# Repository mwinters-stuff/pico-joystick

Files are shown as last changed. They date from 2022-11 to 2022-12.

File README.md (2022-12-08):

# vscode-devcontainer-raspberrypi-pico

## Usage

Clone or download repository, copy the contents of .devcontainer into your project
Remove any existing "build" directory.

Open the folder, and allow the container to build.

# To know
* SDK is installed in /pico-sdk
* All USB devices are exported to container - so the picoprobe can be found and used.
* USB Device /dev/ttyACM0 is exported to container for monitoring

## This container includes
* pico-sdk
* openocd - compiled for picoprobe
* picotool
* bootterm (for serial monitoring) - see https://github.com/wtarreau/bootterm

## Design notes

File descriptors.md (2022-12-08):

# Thrustmaster

```
> sudo usbhid-dump -a3:99 -i0 -t0 | grep -v : | xxd -r -p | hidrd-convert -o spec
Usage Page (Desktop),                           ; Generic desktop controls (01h)
Usage (Joystick),                               ; Joystick (04h, application collection)
Collection (Application),
    Usage Page (Button),                        ; Button (09h)
    Usage Minimum (01h),
    Usage Maximum (10h),
    Logical Minimum (0),
    Logical Maximum (1),
    Physical Minimum (0),
    Physical Maximum (1),
    Report Size (1),
    Report Count (16),
    Input (Variable),
    Usage Page (Desktop),                       ; Generic desktop controls (01h)
    Usage (Hat Switch),                         ; Hat switch (39h, dynamic value)
    Logical Minimum (0),
    Logical Maximum (7),
    Physical Minimum (0),
    Physical Maximum (315),
    Unit (Degrees),
    Report Size (4),
    Report Count (1),
    Input (Variable, Null State),
    Input (Constant),
    Usage Page (Desktop),                       ; Generic desktop controls (01h)
    Usage (X),                                  ; X (30h, dynamic value)
    Logical Minimum (0),
    Logical Maximum (16383),
    Physical Minimum (0),
    Physical Maximum (16383),
    Unit,
    Report Size (14),
    Report Count (1),
    Input (Variable),
    Report Size (2),
    Input (Constant),
    Usage (Y),                                  ; Y (31h, dynamic value)
    Report Size (14),
    Input (Variable),
    Report Size (2),
    Input (Constant),
    Usage (Rz),                                 ; Rz (35h, dynamic value)
    Usage (Slider),                             ; Slider (36h, dynamic value)
    Logical Minimum (0),
    Logical Maximum (255),
    Physical Minimum (0),
    Physical Maximum (255),
    Unit,
    Report Size (8),
    Report Count (2),
    Input (Variable),
    Usage Page (FF00h),                         ; FF00h, vendor-defined
    Logical Maximum (65535),
    Usage (01h),
    Report Size (8),
    Report Count (4),
    Feature (Variable, No Preferred, Volatile),
End Collection
```

# CAT Stick.
mwinters@mwinters-nz-ll:~/src/hidrd$ sudo usbhid-dump -a3:101 -i0 -t0 | grep -v : | xxd -r -p | hidrd-convert -o spec
```
Usage Page (Desktop),       ; Generic desktop controls (01h)
Usage (Joystick),           ; Joystick (04h, application collection)
Collection (Application),
    Report ID (12),
    Usage (X),              ; X (30h, dynamic value)
    Logical Minimum (1),
    Logical Maximum (2047),
    Report Size (11),
    Report Count (1),
    Input (Variable),
    Logical Minimum (0),
    Logical Maximum (31),
    Report Size (5),
    Report Count (1),
    Input (Constant),
    Usage (Y),              ; Y (31h, dynamic value)
    Logical Minimum (1),
    Logical Maximum (2047),
    Report Size (11),
    Report Count (1),
    Input (Variable),
    Logical Minimum (0),
    Logical Maximum (31),
    Report Size (5),
    Report Count (1),
    Input (Constant),
    Usage Page (Button),    ; Button (09h)
    Usage Minimum (01h),
    Usage Maximum (08h),
    Logical Minimum (0),
    Logical Maximum (1),
    Report Size (1),
    Report Count (8),
    Input (Variable),
End Collection,
Usage Page (Desktop),       ; Generic desktop controls (01h)
Usage (Joystick),           ; Joystick (04h, application collection)
Collection (Application),
    Report ID (13),
    Usage (X),              ; X (30h, dynamic value)
    Logical Minimum (1),
    Logical Maximum (2047),
    Report Size (11),
    Report Count (1),
    Input (Variable),
    Logical Minimum (0),
    Logical Maximum (31),
    Report Size (5),
    Report Count (1),
    Input (Constant),
    Usage (Y),              ; Y (31h, dynamic value)
    Logical Minimum (1),
    Logical Maximum (2047),
    Report Size (11),
    Report Count (1),
    Input (Variable),
    Logical Minimum (0),
    Logical Maximum (31),
    Report Size (5),
    Report Count (1),
    Input (Constant),
    Usage (Z),              ; Z (32h, dynamic value)
    Logical Minimum (1),
    Logical Maximum (2047),
    Report Size (11),
    Report Count (1),
    Input (Variable),
    Logical Minimum (0),
    Logical Maximum (31),
    Report Size (5),
    Report Count (1),
    Input (Constant),
    Usage (Slider),         ; Slider (36h, dynamic value)
    Logical Minimum (1),
    Logical Maximum (2047),
    Report Size (11),
    Report Count (1),
    Input (Variable),
    Logical Minimum (0),
    Logical Maximum (31),
    Report Size (5),
    Report Count (1),
    Input (Constant),
    Usage (Slider),         ; Slider (36h, dynamic value)
    Logical Minimum (1),
    Logical Maximum (2047),
    Report Size (11),
    Report Count (1),
    Input (Variable),
    Logical Minimum (0),
    Logical Maximum (31),
    Report Size (5),
    Report Count (1),
    Input (Constant),
    Usage Page (Button),    ; Button (09h)
    Usage Minimum (01h),
    Usage Maximum (10h),
    Logical Minimum (0),
    Logical Maximum (1),
    Report Size (1),
    Report Count (16),
    Input (Variable),
End Collection,
Usage Page (FF00h),         ; FF00h, vendor-defined
Usage (01h),
Collection (Application),
    Report ID (8),
    Logical Minimum (0),
    Logical Maximum (255),
    Report Size (8),
    Report Count (7),
    Usage (01h),
    Output (Variable),
    Usage (01h),
    Report Count (7),
    Input (Variable),
End Collection,
Usage Page (FF00h),         ; FF00h, vendor-defined
Usage (01h),
Collection (Application),
    Report ID (4),
    Logical Minimum (0),
    Logical Maximum (255),
    Report Size (8),
    Report Count (63),
    Usage (01h),
    Output (Variable),
    Usage (01h),
    Report Count (63),
    Input (Variable),
End Collection
```

# Logitech F310 - Direct Input Mode
```
athew@gonzalas:~$ sudo usbhid-dump -a3:11 -i0 -t0 | grep -v : | xxd -r -p | hidrd-convert -o spec
Usage Page (Desktop),                   ; Generic desktop controls (01h)
Usage (Joystick),                       ; Joystick (04h, application collection)
Collection (Application),
    Collection (Logical),
        Report Size (8),
        Report Count (4),
        Logical Minimum (0),
        Logical Maximum (255),
        Physical Minimum (0),
        Physical Maximum (255),
        Usage (X),                      ; X (30h, dynamic value)
        Usage (Y),                      ; Y (31h, dynamic value)
        Usage (Z),                      ; Z (32h, dynamic value)
        Usage (Rz),                     ; Rz (35h, dynamic value)
        Input (Variable),
        Report Size (4),
        Report Count (1),
        Logical Maximum (7),
        Physical Maximum (315),
        Unit (Degrees),
        Usage (Hat Switch),             ; Hat switch (39h, dynamic value)
        Input (Variable, Null State),
        Unit,
        Report Size (1),
        Report Count (12),
        Logical Maximum (1),
        Physical Maximum (1),
        Usage Page (Button),            ; Button (09h)
        Usage Minimum (01h),
        Usage Maximum (0Ch),
        Input (Variable),
        Usage Page (FF00h),             ; FF00h, vendor-defined
        Report Size (1),
        Report Count (16),
        Logical Maximum (1),
        Physical Maximum (1),
        Usage (01h),
        Input (Variable),
    End Collection,
    Collection (Logical),
        Report Size (8),
        Report Count (7),
        Physical Maximum (255),
        Logical Maximum (255),
        Usage (02h),
        Output (Variable),
    End Collection,
```

# ASUS Nexus Player Gamepad.
```
0x0A, 0xDE, 0x0A,  // Usage (0x0ADE)
0xAE, 0x0A, 0x0A,  // Unknown (bTag: 0x0A, bType: 0x03)
0x00,              // Unknown (bTag: 0x00, bType: 0x00)
0x1A, 0x7D, 0xDA,  // Usage Minimum (0xDA7D)
0x71, 0x11,        // Unknown (bTag: 0x07, bType: 0x00)
0x0A, 0x0F, 0xBE,  // Usage (0xBE0F)
0x05, 0xBE,        // Usage Page (Reserved 0xBE)
0xED, 0xDC,        // Unknown (bTag: 0x0E, bType: 0x03)
0x0E, 0x0E, 0x0E,  // Unknown (bTag: 0x00, bType: 0x03)
0x05, 0x01,        // Usage Page (Generic Desktop Ctrls)
0x09, 0x05,        // Usage (Game Pad)
0xA1, 0x01,        // Collection (Application)
0x85, 0x01,        //   Report ID (1)
0x05, 0x09,        //   Usage Page (Button)
0x0A, 0x01, 0x00,  //   Usage (0x01)
0x0A, 0x02, 0x00,  //   Usage (0x02)
0x0A, 0x04, 0x00,  //   Usage (0x04)
0x0A, 0x05, 0x00,  //   Usage (0x05)
0x0A, 0x07, 0x00,  //   Usage (0x07)
0x0A, 0x08, 0x00,  //   Usage (0x08)
0x0A, 0x0E, 0x00,  //   Usage (0x0E)
0x0A, 0x0F, 0x00,  //   Usage (0x0F)
0x0A, 0x0D, 0x00,  //   Usage (0x0D)
0x05, 0x0C,        //   Usage Page (Consumer)
0x0A, 0x24, 0x02,  //   Usage (AC Back)
0x0A, 0x23, 0x02,  //   Usage (AC Home)
0x15, 0x00,        //   Logical Minimum (0)
0x25, 0x01,        //   Logical Maximum (1)
0x75, 0x01,        //   Report Size (1)
0x95, 0x0B,        //   Report Count (11)
0x81, 0x02,        //   Input (Data,Var,Abs,No Wrap,Linear,Preferred State,No Null Position)
0x75, 0x01,        //   Report Size (1)
0x95, 0x01,        //   Report Count (1)
0x81, 0x03,        //   Input (Const,Var,Abs,No Wrap,Linear,Preferred State,No Null Position)
0x05, 0x01,        //   Usage Page (Generic Desktop Ctrls)
0x75, 0x04,        //   Report Size (4)
0x95, 0x01,        //   Report Count (1)
0x25, 0x07,        //   Logical Maximum (7)
0x46, 0x3B, 0x01,  //   Physical Maximum (315)
0x66, 0x14, 0x00,  //   Unit (System: English Rotation, Length: Centimeter)
0x09, 0x39,        //   Usage (Hat switch)
0x81, 0x42,        //   Input (Data,Var,Abs,No Wrap,Linear,Preferred State,Null State)
0x66, 0x00, 0x00,  //   Unit (None)
0xA1, 0x00,        //   Collection (Physical)
0x09, 0x30,        //     Usage (X)
0x09, 0x31,        //     Usage (Y)
0x09, 0x32,        //     Usage (Z)
0x09, 0x35,        //     Usage (Rz)
0x05, 0x02,        //     Usage Page (Sim Ctrls)
0x09, 0xC5,        //     Usage (Brake)
0x09, 0xC4,        //     Usage (Accelerator)
0x15, 0x00,        //     Logical Minimum (0)
0x26, 0xFF, 0x00,  //     Logical Maximum (255)
0x35, 0x00,        //     Physical Minimum (0)
0x46, 0xFF, 0x00,  //     Physical Maximum (255)
0x75, 0x08,        //     Report Size (8)
0x95, 0x06,        //     Report Count (6)
0x81, 0x02,        //     Input (Data,Var,Abs,No Wrap,Linear,Preferred State,No Null Position)
0xC0,              //   End Collection
0x85, 0x02,        //   Report ID (2)
0x05, 0x08,        //   Usage Page (LEDs)
0x0A, 0x01, 0x00,  //   Usage (Num Lock)
0x0A, 0x02, 0x00,  //   Usage (Caps Lock)
0x0A, 0x03, 0x00,  //   Usage (Scroll Lock)
0x0A, 0x04, 0x00,  //   Usage (Compose)
0x15, 0x00,        //   Logical Minimum (0)
0x25, 0x01,        //   Logical Maximum (1)
0x75, 0x01,        //   Report Size (1)
0x95, 0x04,        //   Report Count (4)
0x91, 0x02,        //   Output (Data,Var,Abs,No Wrap,Linear,Preferred State,No Null Position,Non-volatile)
0x75, 0x04,        //   Report Size (4)
0x95, 0x01,        //   Report Count (1)
0x91, 0x03,        //   Output (Const,Var,Abs,No Wrap,Linear,Preferred State,No Null Position,Non-volatile)
0xC0,              // End Collection
0x05, 0x01,        // Usage Page (Generic Desktop Ctrls)
0x09, 0x05,        // Usage (Game Pad)
0xA1, 0x01,        // Collection (Application)
0x85, 0x03,        //   Report ID (3)
0x05, 0x06,        //   Usage Page (Generic Dev Ctrls)
0x09, 0x20,        //   Usage (Battery Strength)
0x15, 0x00,        //   Logical Minimum (0)
0x26, 0xFF, 0x00,  //   Logical Maximum (255)
0x75, 0x08,        //   Report Size (8)
0x95, 0x01,        //   Report Count (1)
0x81, 0x02,        //   Input (Data,Var,Abs,No Wrap,Linear,Preferred State,No Null Position)
0x06, 0xBC, 0xFF,  //   Usage Page (Vendor Defined 0xFFBC)
0x0A, 0xAD, 0xBD,  //   Usage (0xBDAD)
0x75, 0x08,        //   Report Size (8)
0x95, 0x06,        //   Report Count (6)
0x81, 0x02,        //   Input (Data,Var,Abs,No Wrap,Linear,Preferred State,No Null Position)
0x06, 0x78, 0xFF,  //   Usage Page (Vendor Defined 0xFF78)
0x0A, 0x03, 0x02,  //   Usage (0x0203)
0x75, 0x08,        //   Report Size (8)
0x95,              //   Report Count (0)

// 214 bytes
```

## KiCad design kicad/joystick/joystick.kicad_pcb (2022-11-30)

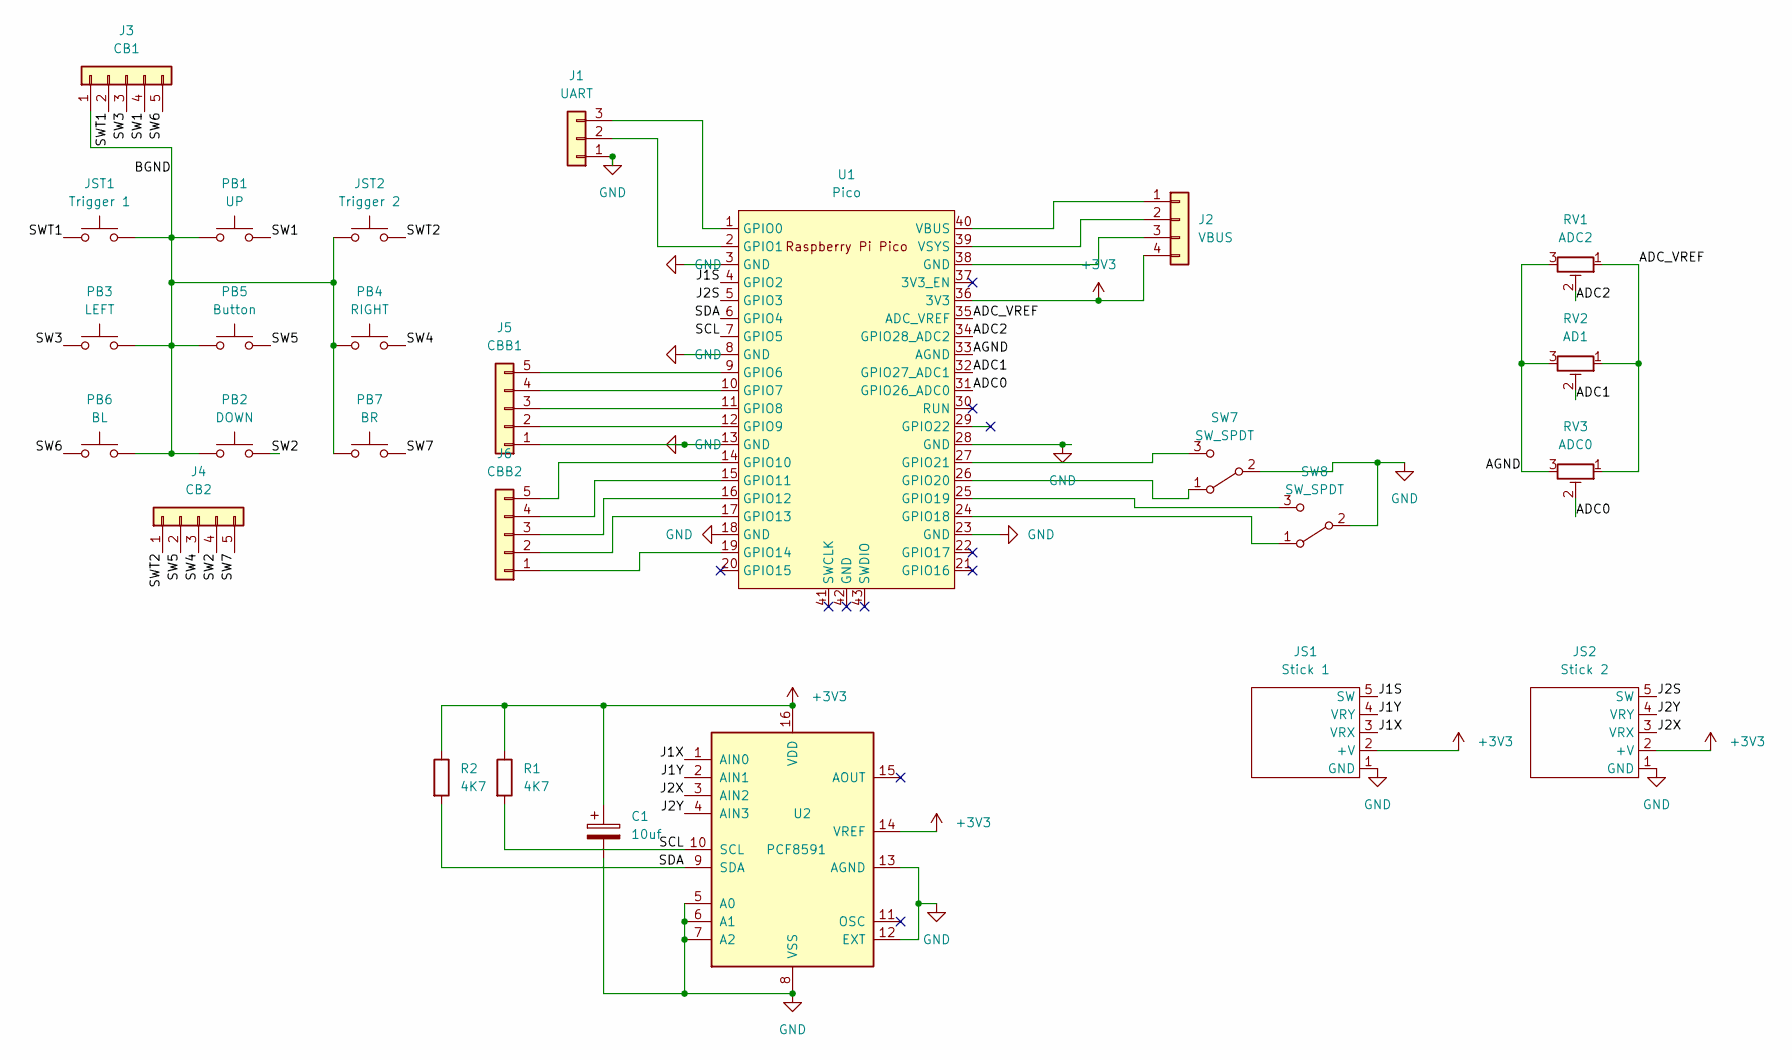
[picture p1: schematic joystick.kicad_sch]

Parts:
C1: 10uf; CP_Radial_D5.0mm_P2.50mm
J1: UART; PinHeader_1x03_P2.54mm_Vertical
J2: VBUS; PinHeader_1x04_P2.54mm_Vertical
J3: CB1; PinHeader_1x05_P2.54mm_Vertical
J4: CB2; PinHeader_1x05_P2.54mm_Vertical
J5: CBB1; PinSocket_1x05_P2.54mm_Vertical
J6: CBB2; PinSocket_1x05_P2.54mm_Vertical
JS1: Stick 1; Joystick
JS2: Stick 2; Joystick
JST1: Trigger 1; SW_PUSH_6mm_SP
JST2: Trigger 2; SW_PUSH_6mm_SP
PB1: UP; SW_PUSH_6mm_SP
PB2: DOWN; SW_PUSH_6mm_SP
PB3: LEFT; SW_PUSH_6mm_SP
PB4: RIGHT; SW_PUSH_6mm_SP
PB5: Button; SW_PUSH_6mm_SP
PB6: BL; SW_PUSH_6mm_SP
PB7: BR; SW_PUSH_6mm_SP
R1, R2: 4K7; R_Axial_DIN0207_L6.3mm_D2.5mm_P10.16mm_Horizontal
RV1: ADC2; Potentiometer_Runtron_RM-065_Vertical
RV2: AD1; Potentiometer_Runtron_RM-065_Vertical
RV3: ADC0; Potentiometer_Runtron_RM-065_Vertical
SW7, SW8: SW_SPDT; PinHeader_1x03_P2.54mm_Vertical
U1: Pico; RPi_Pico_SMD_TH
U2: PCF8591; DIP-16_W7.62mm

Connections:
+3V3: C1.1, J2.4, JS1.2 (+V), JS2.2 (+V), R1.1, R2.1, U1.36 (3V3), U2.14 (VREF), U2.16 (VDD)
/ADC0: RV3.2, U1.31 (GPIO26_ADC0)
/ADC1: RV2.2, U1.32 (GPIO27_ADC1)
/ADC2: RV1.2, U1.34 (GPIO28_ADC2)
/ADC_VREF: RV1.1, RV2.1, RV3.1, U1.35 (ADC_VREF)
/AGND: RV1.3, RV2.3, RV3.3, U1.33 (AGND)
/BGND: J3.1, JST1.2, JST2.1, PB1.1, PB2.1, PB3.2, PB4.1, PB5.1, PB6.2, PB7.1
/J1S: JS1.5 (SW), U1.4 (GPIO2)
/J1X: JS1.3 (VRX), U2.1 (AIN0)
/J1Y: JS1.4 (VRY), U2.2 (AIN1)
/J2S: JS2.5 (SW), U1.5 (GPIO3)
/J2X: JS2.3 (VRX), U2.3 (AIN2)
/J2Y: JS2.4 (VRY), U2.4 (AIN3)
/SCL: R1.2, U1.7 (GPIO5), U2.10 (SCL)
/SDA: R2.2, U1.6 (GPIO4), U2.9 (SDA)
/SW1: J3.4, PB1.2
/SW2: J4.4, PB2.2
/SW3: J3.3, PB3.1
/SW4: J4.3, PB4.2
/SW5: J4.2, PB5.2
/SW6: J3.5, PB6.1
/SW7: J4.5, PB7.2
/SWT1: J3.2, JST1.1
/SWT2: J4.1, JST2.2
GND: C1.2, J1.1, J5.1, JS1.1 (GND), JS2.1 (GND), SW7.2 (B), SW8.2 (B), U1.3 (GND), U1.8 (GND), U1.13 (GND), U1.18 (GND), U1.23 (GND), U1.28 (GND), U2.5 (A0), U2.6 (A1), U2.7 (A2), U2.8 (VSS), U2.12 (EXT), U2.13 (AGND)
unnamed: J1.2, U1.2 (GPIO1)
unnamed: J1.3, U1.1 (GPIO0)
unnamed: J5.2, U1.12 (GPIO9)
unnamed: J5.3, U1.11 (GPIO8)
unnamed: J5.4, U1.10 (GPIO7)
unnamed: J5.5, U1.9 (GPIO6)
unnamed: J6.1, U1.19 (GPIO14)
unnamed: J6.2, U1.17 (GPIO13)
unnamed: J6.3, U1.16 (GPIO12)
unnamed: J6.4, U1.15 (GPIO11)
unnamed: J6.5, U1.14 (GPIO10)
unnamed: SW7.1 (A), U1.26 (GPIO20)
unnamed: SW7.3 (C), U1.27 (GPIO21)
unnamed: SW8.1 (A), U1.24 (GPIO18)
unnamed: SW8.3 (C), U1.25 (GPIO19)
unnamed: J2.3, U1.38 (GND)
unnamed: J2.2, U1.39 (VSYS)
unnamed: J2.1, U1.40 (VBUS)

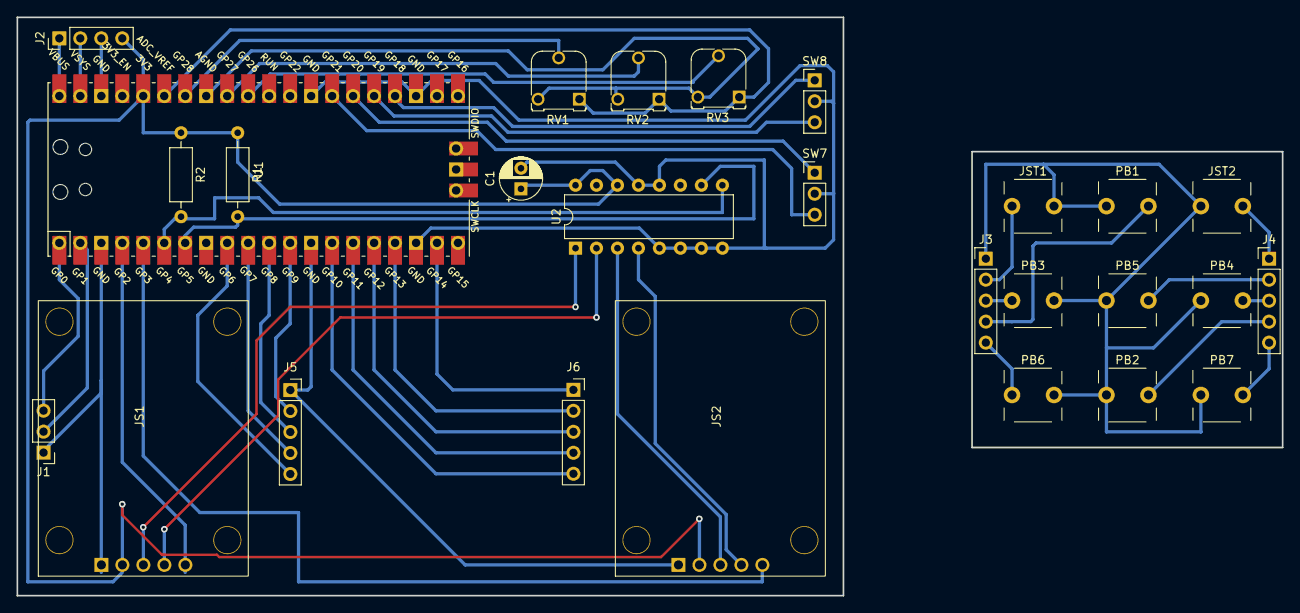
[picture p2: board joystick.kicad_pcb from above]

Board: 2 copper layers, 153.2 x 70.0 mm, 27 parts (0 on the bottom side), 43 nets.

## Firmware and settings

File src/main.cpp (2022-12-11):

/*
 * The MIT License (MIT)
 *
 * Copyright (c) 2019 Ha Thach (tinyusb.org)
 *
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
 */

#include <stdio.h>
#include <stdlib.h>
#include <string>

#include "bsp/board.h"

#include "pico/stdlib.h"
#include "tusb.h"
#include "usb_descriptors.h"
#include "hardware/watchdog.h"
#include "hardware.h"

void hid_task(void);


void serial_print(const char* str);
bool serialReady = false;
static absolute_time_t next_task_time;
#define USB_REPORT_INTERVAL 10

SwitchesPosition switches_position;

/*------------- MAIN -------------*/
int main(void) {
  stdio_init_all();
  board_init();
  tusb_init();

  serial_print("Init\n");

  hardware.begin();
  hardware.led_blink_fast();

  next_task_time =  make_timeout_time_ms(USB_REPORT_INTERVAL);
  hardware.update();
  switches_position = hardware.switches_position();
  // configure_usb();

  watchdog_enable(100, 1);

  while (true) {
    watchdog_update();
    tud_task();  // tinyusb device task
    hardware.update();
    serial_print( hardware.debug().c_str());
    
    if(hardware.switches_position() != switches_position){
      serial_print("Switches Changed, Rebooting\n");
      sleep_ms(1000);
    }
    hid_task();

  }

  return 0;
}


void configure_usb(){

}
//--------------------------------------------------------------------+
// Device callbacks
//--------------------------------------------------------------------+

// Invoked when device is mounted
void tud_mount_cb(void) {
  serial_print("tud_mount_cb\n");
  hardware.led_blink_slow();
}

// Invoked when device is unmounted
void tud_umount_cb(void) {
  serial_print("tud_umount_cb\n");
  hardware.led_blink_fast();
}

// Invoked when usb bus is suspended
// remote_wakeup_en : if host allow us  to perform remote wakeup
// Within 7ms, device must draw an average of current less than 2.5 mA from bus
void tud_suspend_cb(bool remote_wakeup_en) {
  (void)remote_wakeup_en;
  hardware.led_blink_slower();
}

// Invoked when usb bus is resumed
void tud_resume_cb(void) {
  hardware.led_blink_slow();
}

//--------------------------------------------------------------------+
// USB HID
//--------------------------------------------------------------------+

static void send_hid_report(uint8_t report_id) {
  // skip if hid is not ready yet
  if (!tud_hid_ready()) return;

  switch (report_id) {
    case REPORT_ID_JOYSTICK_SINGLE: {
      // printf("send_hid_report joystick left\n");
      static HID_JoystickReport_Data_t report = {0, 0, 0};

      report.xAxis1 = hardware.stick_left_x();
      report.yAxis1 = hardware.stick_left_y();

      report.buttons.bits.trigger = hardware.button_down(baBottomLeft) ? 1 : 0;
      report.buttons.bits.thumb = hardware.stick_left_button_down();
      tud_hid_report(REPORT_ID_JOYSTICK_SINGLE, &report, sizeof(report));
      // button = (button + 1) & 0x07; // limit button to the range 0..7

    } 
    break;

     case REPORT_ID_JOYSTICK_LEFT: {
      // printf("send_hid_report joystick left\n");
      static HID_JoystickReport_Data_t report = {0, 0, 0};

      report.xAxis1 = hardware.stick_left_x();
      report.yAxis1 = hardware.stick_left_y();

      report.buttons.bits.trigger = hardware.button_down(baBottomLeft) ? 1 : 0;
      report.buttons.bits.thumb = hardware.stick_left_button_down();
      tud_hid_report(REPORT_ID_JOYSTICK_LEFT, &report, sizeof(report));
      // button = (button + 1) & 0x07; // limit button to the range 0..7

    } 
    break;

    case REPORT_ID_JOYSTICK_RIGHT: {
      static HID_JoystickReport_Data_t report = {0, 0, 0};

      report.xAxis1 = hardware.stick_right_x();
      report.yAxis1 = hardware.stick_right_y();

      report.buttons.bits.trigger = hardware.button_down(baBottomRight) ? 1 : 0;
      report.buttons.bits.thumb = hardware.stick_right_button_down();
      tud_hid_report(REPORT_ID_JOYSTICK_RIGHT, &report, sizeof(report));
      // button = (button + 1) & 0x07; // limit button to the range 0..7

    } 
    break;


    case REPORT_ID_GAMEPAD:
    {
      // use to avoid send multiple consecutive zero report for keyboard
      static bool has_gamepad_key = false;

      hid_gamepad_custom_report_t report =
      {
        .x   = 0, .y = 0, .rx = 0, .ry = 0,
        .hat = 0, .buttons = 0
      };

      report.x = hardware.stick_left_x();
      report.y = hardware.stick_left_y();
      report.rx = hardware.stick_right_x();
      report.ry = hardware.stick_right_y();

      if(hardware.stick_left_button_down())
      {
        report.buttons = GAMEPAD_BUTTON_TL;
      }

      if(hardware.stick_right_button_down())
      {
        report.buttons |= GAMEPAD_BUTTON_TR;
      }


      report.hat = GAMEPAD_HAT_CENTERED;
      switch(hardware.last_button_down()){
        case baTopLeft:
          report.hat = GAMEPAD_HAT_UP_LEFT;
        break;
        case baTopMiddle:
          report.hat = GAMEPAD_HAT_UP;
        break;
        case baTopRight:
          report.hat = GAMEPAD_HAT_UP_RIGHT;
        break;
        case baMiddleLeft:
          report.hat = GAMEPAD_HAT_LEFT;
        break;
        case baMiddleMiddle:
          report.buttons |= GAMEPAD_BUTTON_START;
        break;
        case baMiddleRight:
          report.hat = GAMEPAD_HAT_RIGHT;
        break;
        case baBottomLeft:
          report.hat = GAMEPAD_HAT_DOWN_LEFT;
        break;
        case baBottomMiddle:
          report.hat = GAMEPAD_HAT_DOWN;
        break;
        case baBottomRight:
          report.hat = GAMEPAD_HAT_DOWN_RIGHT;
        break;

      }
      tud_hid_report(REPORT_ID_GAMEPAD, &report, sizeof(report));
    }
    break;    
    default:
      break;
  }
}

// Every 10ms, we will sent 1 report for each HID profile (keyboard, mouse etc ..)
// tud_hid_report_complete_cb() is used to send the next report after previous one is complete
void hid_task(void) {
  if (absolute_time_diff_us(get_absolute_time(), next_task_time) > 0){
    // printf("hid_task No Time %" PRId64 " %" PRIu32 " %" PRIu32 "\n", atd, to_ms_since_boot(at), to_ms_since_boot(next_task_time));
    return;  // not enough time
  } 

  next_task_time = make_timeout_time_ms(USB_REPORT_INTERVAL);
  // printf("hid_task %" PRIu32 "\n", to_ms_since_boot(get_absolute_time()));


  // Remote wakeup
  if (tud_suspended() && hardware.button_down(baBottomMiddle)) {
    // Wake up host if we are in suspend mode
    // and REMOTE_WAKEUP feature is enabled by host
    tud_remote_wakeup();
  } else {
    // Send the 1st of report chain, the rest will be sent by tud_hid_report_complete_cb()
    
    switch(hardware.switches_position())
    {
      case spTopUpBottomUp:
        send_hid_report(REPORT_ID_JOYSTICK_SINGLE);
        break;
      case spTopDownBottomUp:
        send_hid_report(REPORT_ID_JOYSTICK_LEFT);
        break;
      case spTopUpBottomDown:
        send_hid_report(REPORT_ID_GAMEPAD);
        break;
    }

  }
}

// Invoked when sent REPORT successfully to host
// Application can use this to send the next report
// Note: For composite reports, report[0] is report ID
void tud_hid_report_complete_cb(uint8_t instance, uint8_t const* report, uint8_t len) {
  (void)instance;
  (void)len;

  uint8_t report_id = report[0];
  switch(hardware.switches_position())
  {
    case spTopUpBottomDown:
    case spTopUpBottomUp:
      // send_hid_report(REPORT_ID_JOYSTICK_SINGLE);
      break;
    case spTopDownBottomUp:
      if(report_id == REPORT_ID_JOYSTICK_LEFT)
        send_hid_report(REPORT_ID_JOYSTICK_RIGHT);
      break;
  }
}

// Invoked when received GET_REPORT control request
// Application must fill buffer report's content and return its length.
// Return zero will cause the stack to STALL request
uint16_t tud_hid_get_report_cb(uint8_t instance, uint8_t report_id, hid_report_type_t report_type, uint8_t* buffer, uint16_t reqlen) {
  // TODO not Implemented
  (void)instance;
  (void)report_id;
  (void)report_type;
  (void)buffer;
  (void)reqlen;
  serial_print("tud_hid_get_report_cb\n");

  return 0;
}

// Invoked when received SET_REPORT control request or
// received data on OUT endpoint ( Report ID = 0, Type = 0 )
void tud_hid_set_report_cb(uint8_t instance, uint8_t report_id, hid_report_type_t report_type, uint8_t const* buffer, uint16_t bufsize) {
  (void)instance;
}

// Invoked when cdc when line state changed e.g connected/disconnected
void tud_cdc_line_state_cb(uint8_t itf, bool dtr, bool rts) 
{
  (void)itf;
  (void)rts;

  serialReady = false;
  if (dtr) {
    serialReady = true;
    serial_print("Connected\n");
  }
}

void serial_print(const char* str) {
  if (serialReady) {
    tud_cdc_write_str(str);
  }else{
    printf(str);
  }
}

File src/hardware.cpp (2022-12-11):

#include<sstream>

#include "hardware.h"
#include "pico/binary_info.h"

static const uint8_t buttons[] = {
   GPIO_BUTTON_1_1,GPIO_BUTTON_1_2,GPIO_BUTTON_1_3,
   GPIO_BUTTON_2_1,GPIO_BUTTON_2_2,GPIO_BUTTON_2_3,
   GPIO_BUTTON_3_1,GPIO_BUTTON_3_2,GPIO_BUTTON_3_3,
};

/* Blink pattern
 * - 250 ms  : device not mounted
 * - 1000 ms : device mounted
 * - 2500 ms : device is suspended
 */
enum {
  BLINK_NOT_MOUNTED = 250,
  BLINK_MOUNTED = 1000,
  BLINK_SUSPENDED = 2500,
};

Hardware hardware;

Hardware::Hardware(): i2c(i2c0), pcf8591(){
  blink_interval_ms = 0;
  
}

void Hardware::begin(){


  adc_init();
  adc_gpio_init(26);
  adc_gpio_init(27);
  adc_gpio_init(28);

  i2c_init(i2c, 40 * 1000);
  gpio_set_function(PICO_DEFAULT_I2C_SDA_PIN, GPIO_FUNC_I2C);
  gpio_set_function(PICO_DEFAULT_I2C_SCL_PIN, GPIO_FUNC_I2C);
  gpio_pull_up(PICO_DEFAULT_I2C_SDA_PIN);
  gpio_pull_up(PICO_DEFAULT_I2C_SCL_PIN);
  bi_decl(bi_2pins_with_func(PICO_DEFAULT_I2C_SDA_PIN, PICO_DEFAULT_I2C_SCL_PIN, GPIO_FUNC_I2C));

  if(!pcf8591.begin(i2c)){
    printf("ERROR: PCF8591 Failed to talk\n");
  }
  pcf8591.disableDAC();

  gpio_init(LED_PIN);
  gpio_set_dir(LED_PIN, GPIO_OUT);

  set_gpio_pin_out(GPIO_BUTTON_STICK1);
  set_gpio_pin_out(GPIO_BUTTON_STICK2);
  set_gpio_pin_out(GPIO_SWITCH_1_UP);
  set_gpio_pin_out(GPIO_SWITCH_1_DOWN);
  set_gpio_pin_out(GPIO_SWITCH_2_UP);
  set_gpio_pin_out(GPIO_SWITCH_2_DOWN);

  for(int d =0; d < 9; d++){
    set_gpio_pin_out(buttons[d]);
  }

}

void Hardware::set_gpio_pin_out(uint8_t pin){
  gpio_init(pin);
  gpio_set_dir(pin, GPIO_IN);
  gpio_set_pulls(pin, true, false);
}

std::string Hardware::debug(){
      std::stringstream ss;
      
      const uint adc_max = (1 << 8);
      
      const uint bar_width = 20;
      uint bar_x_pos = adc_stick_1_x_raw * bar_width / adc_max;
      uint bar_y_pos = adc_stick_1_y_raw * bar_width / adc_max;
      ss << "X: [";
      for (int i = 0; i < bar_width; ++i){ 
        ss << (i == bar_x_pos ? 'o' : ' ');
      }
      ss << "]  Y: [";
      for (int i = 0; i < bar_width; ++i){
        ss << (i == bar_y_pos ? 'o' : ' ');
      } 
      ss << "] ";

      bar_x_pos = adc_stick_2_x_raw * bar_width / adc_max;
      bar_y_pos = adc_stick_2_y_raw * bar_width / adc_max;
      ss << "X: [";
      for (int i = 0; i < bar_width; ++i){ 
        ss << (i == bar_x_pos ? 'o' : ' ');
      }
      ss << "]  Y: [";
      for (int i = 0; i < bar_width; ++i){
        ss << (i == bar_y_pos ? 'o' : ' ');
      } 
      ss << "] ("
         << (stick_down1 ? "X" : ".")
         << (stick_down2 ? "X" : ".") << " ";

      for(int d =0; d < 9; d++){
        ss << (button_down((ButtonArray)d) ? "X" : ".");
        if(d == 2 || d == 5){
          ss << "/";
        }
      }

      ss << "/";
      switch(switchesPosition){
        case spTopUpBottomUp:
          ss << "UU";
          break;
        case spTopUpBottomDown:
          ss << "UD";
          break;
        case spTopDownBottomUp:
          ss << "DU";
          break;
        case spTopDownBottomDown:
          ss << "DD";
          break;
      }

      ss << ") " << (int)adc_stick_1_x_raw << " " << (int)adc_stick_1_y_raw << " " << (int)adc_stick_2_x_raw << " " <<  (int)adc_stick_2_y_raw << "          \r";
      return ss.str();
}

void Hardware::update(){
  led_blinking_task();

    if(pcf8591.analogRead4() == PCF8591_I2C_ERROR)
    {
      printf("****I2C Error\n\n\n");
    
    }else{
      adc_stick_1_y_raw = pcf8591.lastRead(0) ^ 0xff;
      adc_stick_1_x_raw = pcf8591.lastRead(1) ;
      adc_stick_2_y_raw = pcf8591.lastRead(2) ^ 0xff;
      adc_stick_2_x_raw = pcf8591.lastRead(3) ;
    }

    stick_down1 = !gpio_get(GPIO_BUTTON_STICK1);
    stick_down2 = !gpio_get(GPIO_BUTTON_STICK2);

    lastButtonDown = baNone;
    for(int d =0; d < 9; d++){
      buttons_down[d] = !gpio_get(buttons[d]);
      if(buttons_down[d]){
        lastButtonDown = (ButtonArray)d;
      }
    }
 
    bool sw1_up = !gpio_get(GPIO_SWITCH_1_UP);
    bool sw1_down = !gpio_get(GPIO_SWITCH_1_DOWN);

    bool sw2_up = !gpio_get(GPIO_SWITCH_2_UP);
    bool sw2_down = !gpio_get(GPIO_SWITCH_2_DOWN);

    if(sw1_up && sw2_up){
      switchesPosition = spTopUpBottomUp;
    }else if(sw1_up && sw2_down){
      switchesPosition = spTopUpBottomDown;
    }else if(sw1_down && sw2_up){
      switchesPosition = spTopDownBottomUp;
    }else if(sw1_down && sw2_down){
      switchesPosition = spTopDownBottomDown;
    }
}

void Hardware::led_blinking_task() {
  // blink is disabled
  if (!blink_interval_ms)
{
    return;
}

  // Blink every interval ms
  if (absolute_time_diff_us(get_absolute_time(), next_blink_time) > 0){
    return;  // not enough time
  } 

  next_blink_time = make_timeout_time_ms(blink_interval_ms);
  led_state = !led_state;
  gpio_put(LED_PIN, led_state);
}

void Hardware::led_blink_slow(){
  blink_interval_ms = BLINK_NOT_MOUNTED;
  next_blink_time = make_timeout_time_ms(blink_interval_ms);
}
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

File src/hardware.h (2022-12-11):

#ifndef _HARDWARE_H
#define _HARDWARE_H

#include <string>
#include <cstdint>

#include "hardware/i2c.h"
#include "hardware/adc.h"
#include "hardware/gpio.h"
#include "sensor/PCF8591.h"

#define LED_PIN PICO_DEFAULT_LED_PIN

#define GPIO_BUTTON_STICK1 2
#define GPIO_BUTTON_STICK2 3

#define GPIO_BUTTON_1_1 9
#define GPIO_BUTTON_1_2 7
#define GPIO_BUTTON_1_3 14

#define GPIO_BUTTON_2_1 8
#define GPIO_BUTTON_2_2 13
#define GPIO_BUTTON_2_3 12

#define GPIO_BUTTON_3_1 6
#define GPIO_BUTTON_3_2 11
#define GPIO_BUTTON_3_3 10

#define GPIO_SWITCH_1_UP   18
#define GPIO_SWITCH_1_DOWN 19

#define GPIO_SWITCH_2_UP   20
#define GPIO_SWITCH_2_DOWN 21


enum SwitchesPosition{
  spTopUpBottomUp,
  spTopDownBottomUp,
  spTopUpBottomDown,
  spTopDownBottomDown,
};

enum ButtonArray{
  baTopLeft,
  baTopMiddle,
  baTopRight,
  baMiddleLeft,
  baMiddleMiddle,
  baMiddleRight,
  baBottomLeft,
  baBottomMiddle,
  baBottomRight,
  baNone,
};

class Hardware{
  private:
    i2c_inst_t* i2c;
    PCF8591 pcf8591;
    uint16_t blink_interval_ms;
    absolute_time_t next_blink_time;
    bool led_state;

    void set_gpio_pin_out(uint8_t pin);
    void led_blinking_task();


    uint8_t adc_stick_1_x_raw;
    uint8_t adc_stick_1_y_raw;
    uint8_t adc_stick_2_x_raw;
    uint8_t adc_stick_2_y_raw; 

    bool stick_down1 = false;
    bool stick_down2 = false;

    bool buttons_down[9] = {false,false,false,false,false,false,false,false,false};
    ButtonArray lastButtonDown = baNone;

    SwitchesPosition switchesPosition;
  
  public:
    Hardware();

    std::string debug();

    void begin();
    void update();

    uint8_t stick_left_x();
    uint8_t stick_left_y();
    bool stick_left_button_down();

    uint8_t stick_right_x();
    uint8_t stick_right_y();
    bool stick_right_button_down();

    bool button_down(const ButtonArray button);
    ButtonArray last_button_down();

    SwitchesPosition switches_position();

    uint16_t analog_pot_0();
    uint16_t analog_pot_1();
    uint16_t analog_pot_2();


    void led_blink_slow();
    void led_blink_slower();
    void led_blink_fast();
    void led_off();
    void led_on();

};

extern Hardware hardware;

#endif
